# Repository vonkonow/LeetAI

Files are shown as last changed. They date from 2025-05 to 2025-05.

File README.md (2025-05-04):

# 🎹 Leet AI – A Tiny Synth Ensemble with AI-Powered Inspiration

Leet AI is a playful, pocket-sized synthesizer concept that explores what happens when many simple instruments work together—like a miniature electronic orchestra. Unlike traditional synths that try to do everything, Leet AI embraces a modular philosophy: multiple open-source, affordable units, each with a specific voice, combining to create something greater than the sum of their parts.

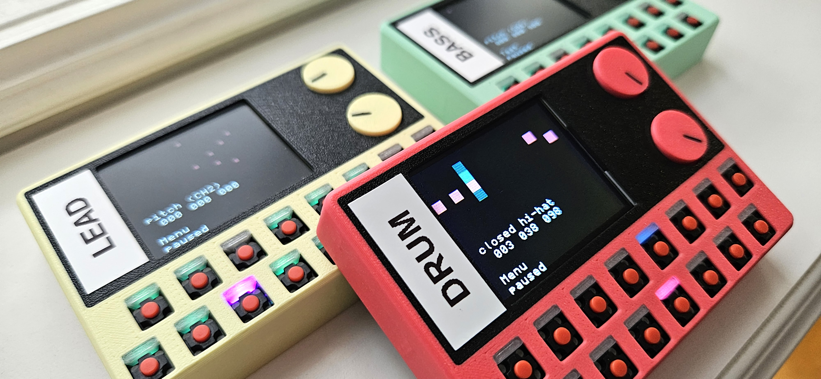
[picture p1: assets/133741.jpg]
group photo


---

## 🌟 Why Leet AI?

Synthesizers can be intimidating. Menus, shift-buttons, and buried features can kill creative flow. Leet AI is an attempt to bring back the fun—tiny instruments you can pick up, jam with, and let the AI surprise you with new melodic ideas. Whether you're a tinkerer, a musician, or just curious about AI and music, this project is for you.

---

## ✨ Features

- 🎵 **AI-powered inspiration**  
  Generate unique melodies, drum patterns, and variations using a diffusion-based AI model.

- 🔧 **Hackable and open-source**  
  Built with CircuitPython on an ESP32-S2—plug it in, and you're editing the firmware like a USB stick.

- 🎛️ **Minimalist design with deep control**  
  Dual rotary encoders with tilt navigation, RGB-backlit keys, and a full-color display keep you focused and in control.

- 📶 **Wireless orchestration**  
  A low-latency protocol keeps multiple units in sync.

- 🔋 **Fully portable**  
  Runs on a rechargeable 1000mAh LiPo battery. Jam anywhere.

---

## 📦 Hardware Specs

- **Size:** 86 x 60 x 15 mm (smaller than a deck of cards!)
- **Keys:** 16 RGB-backlit mechanical keys
- **Microcontroller:** ESP32-S2 (CircuitPython firmware)
- **Display:** 1.8” 160x128 TFT color screen
- **Encoders:** Dual magnetic rotary encoders with tilt function
- **Audio:** High-quality 112dB SNR DAC
- **Connectivity:** MIDI over USB-C, ESP-Now wireless sync
- **Power:** 1000mAh LiPo battery with onboard charging

---

# ▶️ **Demo video** 
demo (https://youtu.be/MnzYHhDXu_o)

---

## 🧪 Build Difficulty 

**Medium.** You'll need SMD soldering skills, a 3D printer, and some patience and curiosity.

---

## 🛠️ Development History

Leet AI combines the best aspects of three earlier open hardware projects: [**leet**](https://vonkonow.com/leet-synthesizer/), [**leet modular**](https://vonkonow.com/leet-modular/), and [**chip champ**](https://vonkonow.com/chipchamp/). Prototypes have evolved through countless iterations—from hand-wired mock-ups to a 12-key prototype and finally to the 16-key design that bridges sequencer and keyboard layouts.

---

## 🚧 Limitations (For Now)

This is still a conceptual prototype. While it’s fully functional for the demo, many features are hardcoded. Here’s what’s next on the roadmap:

- 🎚️ Real-time editing and melody creation  
- 🎵 Higher-fidelity audio engine and custom graphic module
- 🎛️ Instrument selection and sound design (ADSR, filters, etc.)  
- 🧠 Smarter AI integration with automatic Wi-Fi server connection  
- 🎹 Stacked octave mode  
- 🔊 Optional speaker  
- 🎶 AMY synth library support?

---

## 🛒 BOM / Estimated Cost

**Total cost per unit:** ~$24

---

## 💡 Contributing

Got ideas? Want to help improve the synth engine, optimize graphics, or design new enclosures? All contributions—code, hardware, or creative—are welcome!

### ➕ How to Contribute

1. Fork the repo  
2. Try the demo firmware  
3. Submit issues or pull requests  
4. Join the discussion on hardware, AI models, or interface design

---

## 📁 Repository Structure

```
/
├── firmware/       → CircuitPython source code
├── hardware/       → KiCad files, schematics, and PCB layout
├── enclosure/      → 3D models (Rhino & STL)
├── ai-server/      → getMusic setup, scripts and generation tools
├── docs/           → Build guide, BOM, and reference images
└── README.md       → Project overview
```

---

## ❤️ Special Thanks

Huge thanks to the creators and maintainers of open-source tools that made this project possible.  
Special gratitude to [**Adafruit**](https://www.adafruit.com/) for developing [**CircuitPython**](https://circuitpython.org/board/lolin_s2_mini/), which made firmware development approachable, flexible, and fun—even for hardware newcomers.  
Thanks also to the team behind [**synthio**](https://docs.circuitpython.org/en/latest/shared-bindings/synthio/), whose powerful audio capabilities laid the groundwork for expressive, real-time sound generation on microcontrollers.  
And to Microsoft Research for [**getMusic**](https://github.com/microsoft/muzic), and to all the explorers at the intersection of music, AI, and creative technology—your curiosity and generosity continue to inspire.

---

## 🧠 Imagine What’s Next

Leet AI is still early, but the concept is alive. With your feedback, forks, and experiments, this can grow into a truly modular, generative instrument playground.

---

## 🔗 [Visit the project website  ](https://vonkonow.com/leetai/)
## 📂 [Explore the GitHub repository  ](https://github.com/vonkonow/leetai)
## 📸 [Share your builds and music!](https://vonkonow.com/community/)

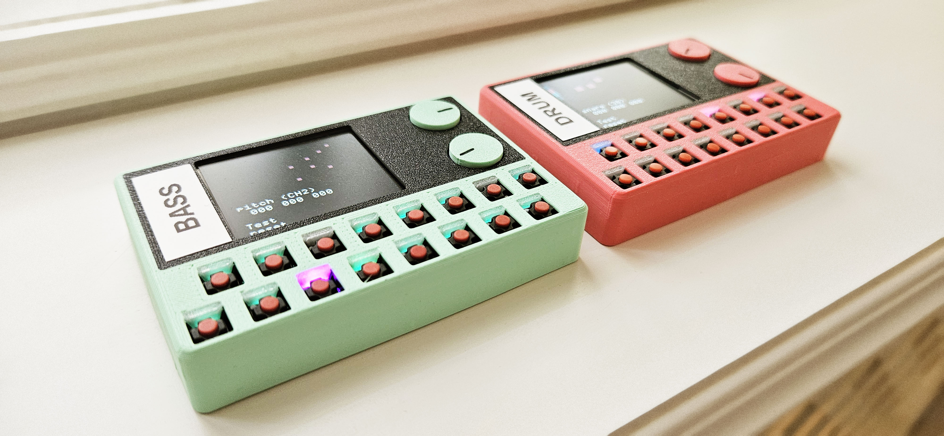
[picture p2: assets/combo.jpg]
DnB


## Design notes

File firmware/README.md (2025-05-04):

# 🎛️ CircuitPython code repository for the LeetAi devices. 
## Usage:
0. First time, you have to connect the device and flash a [CircuitPython image for ESP32S2](https://circuitpython.org/board/lolin_s2_mini/) with [this tool](https://adafruit.github.io/Adafruit_WebSerial_ESPTool/).
1. The device then appears as a new drive. Copy all files and folders in this directory to the device.
2. The code will run automatically and you now have a synth. Edit config/config.py to change its function (see below).

---

## ⚙️ Configuration

The file `config.py` defines each unit's role:

| Function | Description |
|---|---|
| `boss` | Manages the overall song structure |
| `pitch`  | Handles piano and bass lines |
| `pattern`| Drives drum patterns |
| `chords` | Generates chord progressions |
| `arp` | Plays arpeggios that follow chords |

---
## 📁 folder structure:
```
firmware/
├── README.md             # CircuitPython usage & setup instructions
├── boot.py               # Auto-run stub to launch main code on reset
├── code.py               # Entry-point script that wires everything together
│
├── config/               # User-tweakable settings and menus
│   ├── config.py         # Role definitions (boss, arp, chords, etc.) & parameters
│   └── menu.txt          # Text menu definitions shown on the display
│
├── src/                  # Core application code broken into two layers
│   ├── core/             # High-level “unit” drivers (boss, arp, pitch, …)
│   │   ├── boss.py       # Master song/section manager
│   │   ├── chords.py     # Chord progression engine
│   │   ├── pattern.py    # Drum-pattern sequencer
│   │   ├── pitch.py      # Melody & bass line handler
│   │   └── arp.py        # Real-time arpeggiator
│   │
│   └── common/           # Shared utilities & hardware abstractions
│       ├── audio.py      # Synth/audio helper routines
│       ├── hw.py         # Pin/encoder/button abstraction
│       ├── menu.py       # On-screen menu rendering & logic
│       ├── network.py    # Networking (Wi-Fi/OSC/etc.) support
│       ├── song.py       # Song data structures & serialization
│       └── ui.py         # Display & UI primitives
│
├── lib/                  # Bundled 3rd-party CircuitPython libraries/drivers
│   ├── adafruit_midi/      # MIDI bindings
│   ├── adafruit_imageload/ # Image-loading helper
│   ├── adafruit_st7735r.mpy # ST7735 display driver
│   ├── adafruit_wave.mpy    # WAV-sample playback driver
│   ├── neopixel.mpy         # WS2812 “NeoPixel” LED driver
│   └── font.bmp             # Built-in font bitmap
│
└── assets/               # Static resources bundled into filesystem
    ├── images/           # UI graphics, icons, etc.
    ├── audio/            # Samples and wavetable files
    └── arpai.bin         # Demo song (used by boss)
```
---

## 🧰 Hardware Versions

| Version | Features |
|---|---|
| **1.0** | 12 keys + analog encoders |
| **1.1** | 16 keys (new layout) + digital encoders |

---

## 🧪 Development Notes

I've used AI extensively for code refactoring, improvements and error handling. It's a work in progress and likely a few bugs left — but it's definitely more robust than before :)

---
## ❤️ Special Thanks

Huge thanks to the creators and maintainers of open-source tools that made this project possible.  
- Special gratitude to [**Adafruit**](https://www.adafruit.com/) for developing [**CircuitPython**](https://circuitpython.org/board/lolin_s2_mini/), which made firmware development approachable, flexible, and fun—even for hardware newcomers.  
- Thanks also to the team behind [**synthio**](https://docs.circuitpython.org/en/latest/shared-bindings/synthio/), whose powerful audio capabilities laid the groundwork for expressive, real-time sound generation on microcontrollers.  
- And to Microsoft Research for [**getMusic**](https://github.com/microsoft/muzic), and to all the explorers at the intersection of music, AI, and creative technology—your curiosity and generosity continue to inspire.

---
## 🚀 Future Development

Plenty remains to be done. The current demo uses mostly hard-coded elements, so unlocking its full potential will require:

- 🎼 **Melody & pattern editor**
- 🎧 **Audio optimization**  *(Better sample rates, pitch control, lower CPU usage)*
- 🖼️ **Optimized graphics**  *(Smoother animations with less CPU load)*
- 🎚️ **Instrument sound selection and parameter tuning**  *(Velocity, bend, swing, ADSR, filters)*
- 🔀 **Stacked octave mode**  *(Multiple units act as one extended synth)*
- 🌐 **Ai server connection**  *(Currently manual)*
- 🔊 **Maybe a built-in speaker?**
- 🎵 **AMY synth library integration?**

I will probably start with a custom circuitpython fork with new libraries for audio and graphics...

---
## 💡 Contributing

Got ideas? Want to help improve the synth engine, optimize graphics, or design new enclosures? All contributions—code, hardware, or creative—are welcome!

### ➕ How to Contribute

1. Fork the repo  
2. Try the demo firmware  
3. Submit issues or pull requests  
4. Join the discussion on hardware, AI models, or interface design

### 🧠 Imagine What's Next

Leet AI is still early, but the concept is alive. With your feedback, forks, and experiments, this can grow into a truly modular, generative instrument playground.

---

🔗 [Visit the project website  ](https://vonkonow.com/leetai/)
📂 [Explore the GitHub repository  ](https://github.com/vonkonow/leetai)
📸 [Share your builds and music!](https://vonkonow.com/community/)

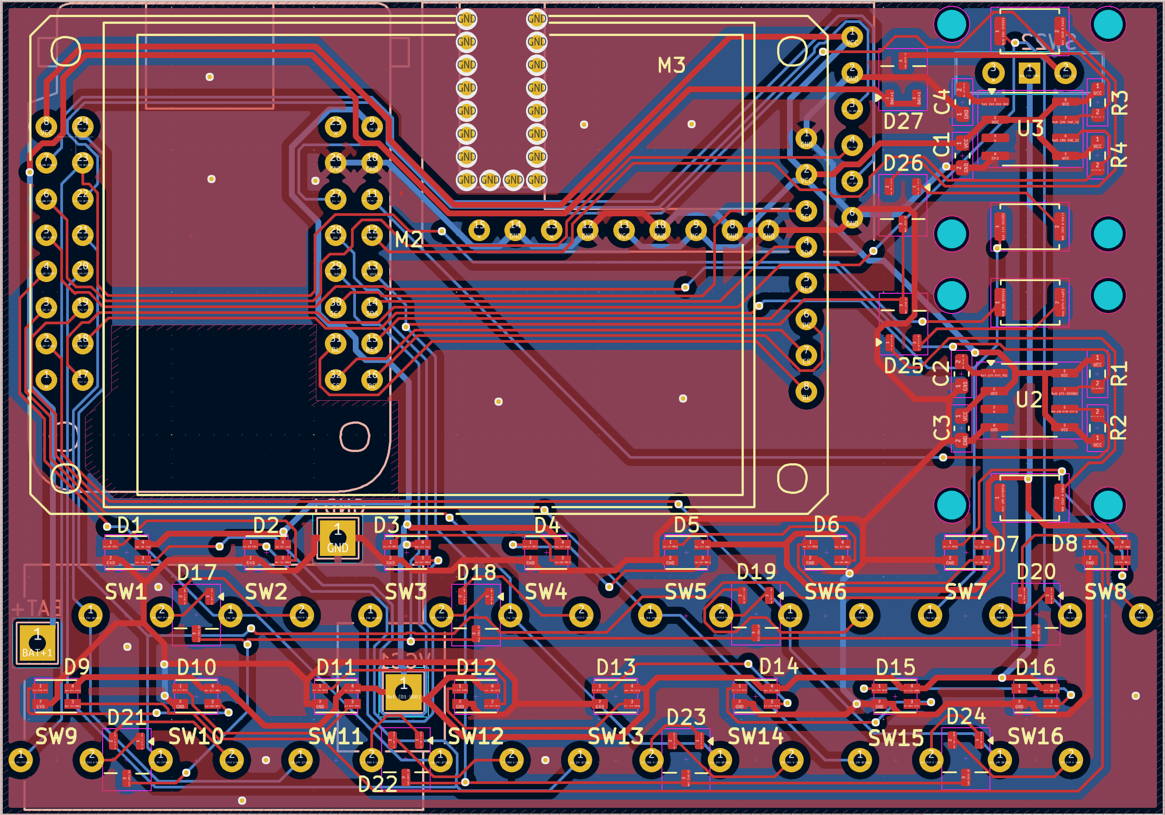
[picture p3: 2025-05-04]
hardware/_pcb.png

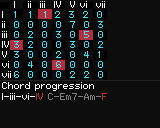
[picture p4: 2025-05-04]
firmware/assets/images/chord3.bmp

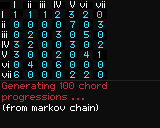
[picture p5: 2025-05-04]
firmware/assets/images/generate.bmp

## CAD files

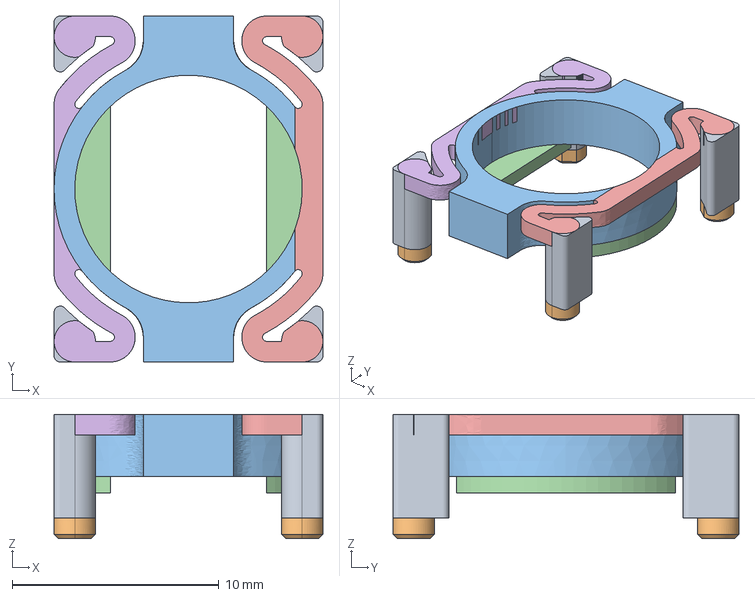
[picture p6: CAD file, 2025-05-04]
enclosure/encoder_main.stp
13.0 x 16.7 x 6.00 mm

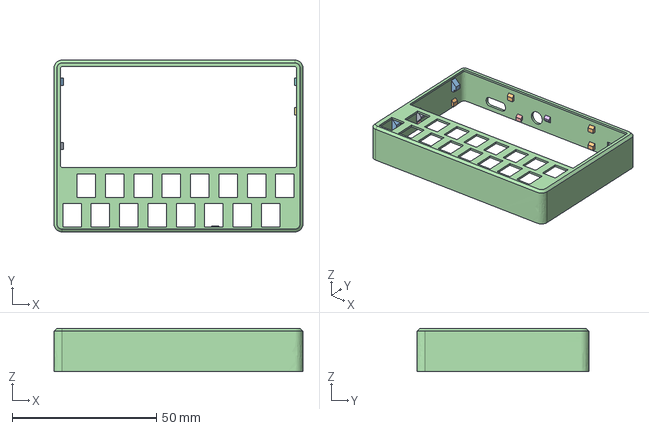
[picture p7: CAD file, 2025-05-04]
enclosure/case_main.stp
86.2 x 59.5 x 15.0 mm

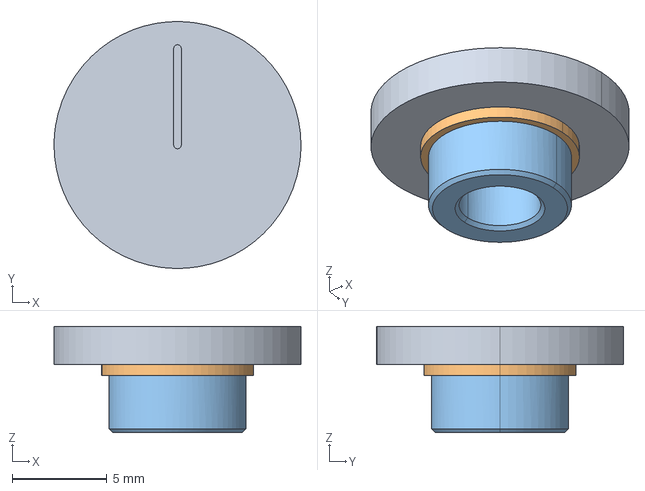
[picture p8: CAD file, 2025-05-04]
enclosure/encoder_knob.stp
13.0 x 13.0 x 5.60 mm

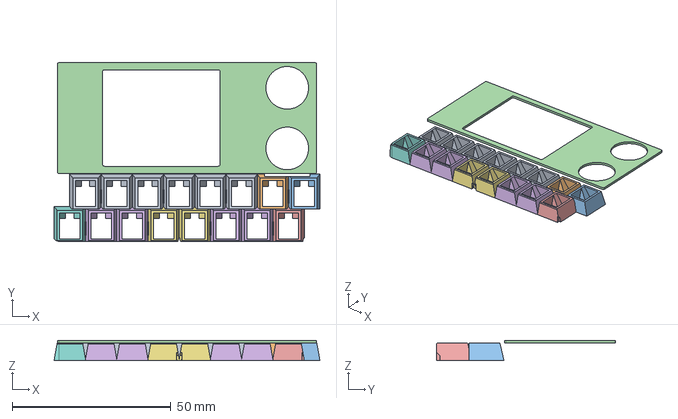
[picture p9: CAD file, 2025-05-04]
enclosure/case_black.stp
83.7 x 56.2 x 6.40 mm

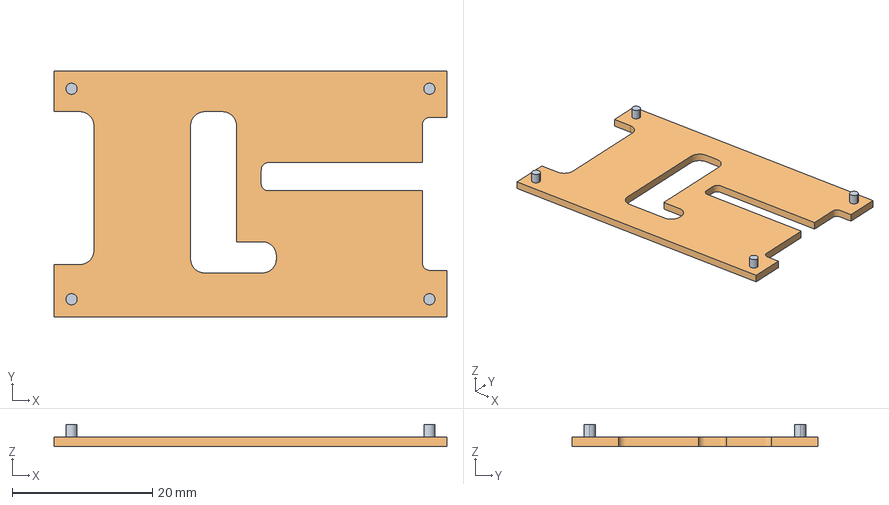
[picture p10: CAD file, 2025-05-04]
enclosure/support_lcd.stp
56.0 x 35.0 x 3.18 mm

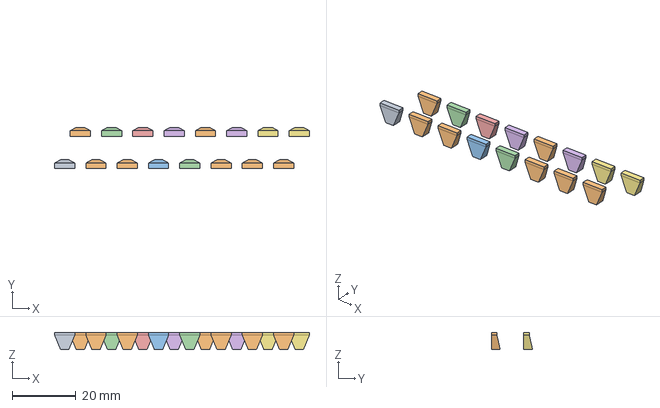
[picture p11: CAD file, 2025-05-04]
enclosure/case_led.stp
80.1 x 13.0 x 5.38 mm

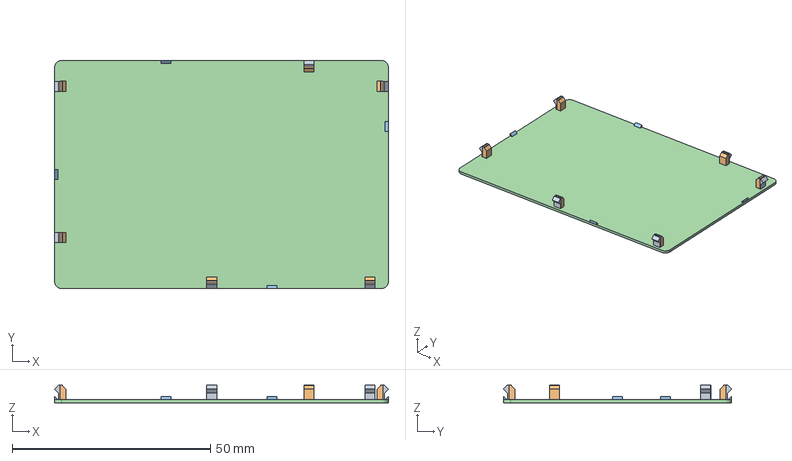
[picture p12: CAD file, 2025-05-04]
enclosure/case_lid.stp
84.2 x 57.5 x 4.50 mm

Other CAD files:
enclosure/case_black.stl
enclosure/case_led.stl
enclosure/case_lid.stl
enclosure/case_main.stl
enclosure/encoder_knob.stl
enclosure/encoder_main.stl
enclosure/support_lcd.stl

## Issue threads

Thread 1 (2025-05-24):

BOM? Charger chip?

GeoffreyPlitt, 2025-05-24:
Cool project!
Can you add a BOM?
What's the part# of the charger chip?

vonkonow, 2025-06-01:
Checkout https://vonkonow.com/leetai/ that has a simple bom.
the charger is a pcb with TP4056, like this: https://www.aliexpress.com/item/1005004427739715.html?

Closed 2025-06-01.

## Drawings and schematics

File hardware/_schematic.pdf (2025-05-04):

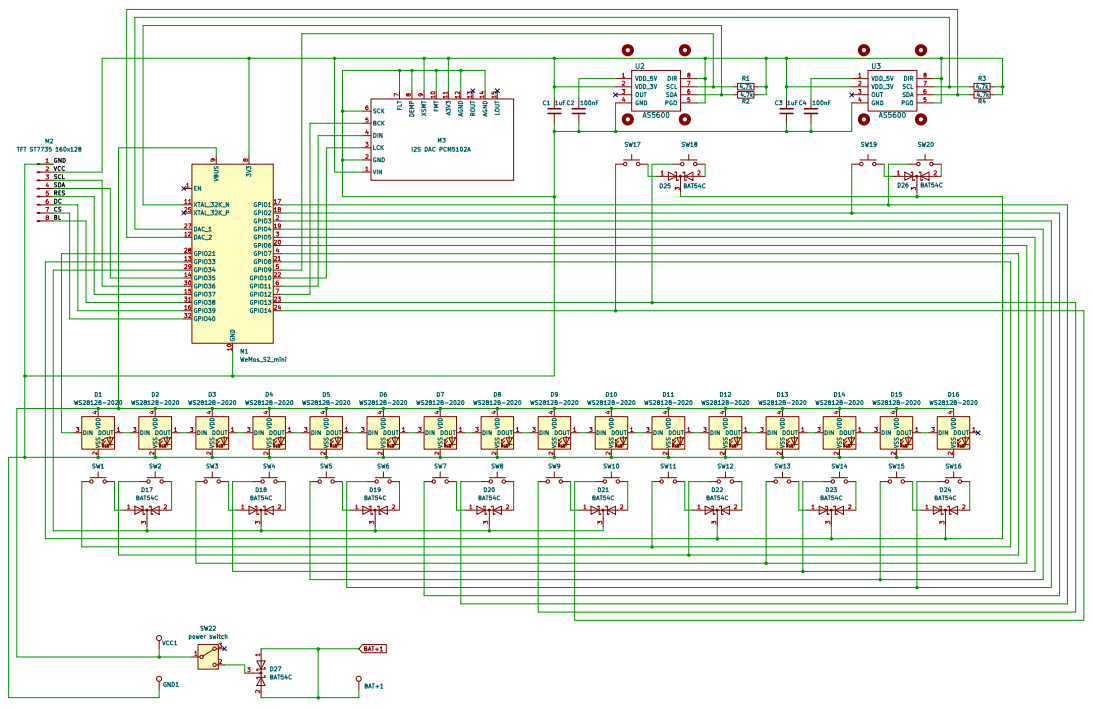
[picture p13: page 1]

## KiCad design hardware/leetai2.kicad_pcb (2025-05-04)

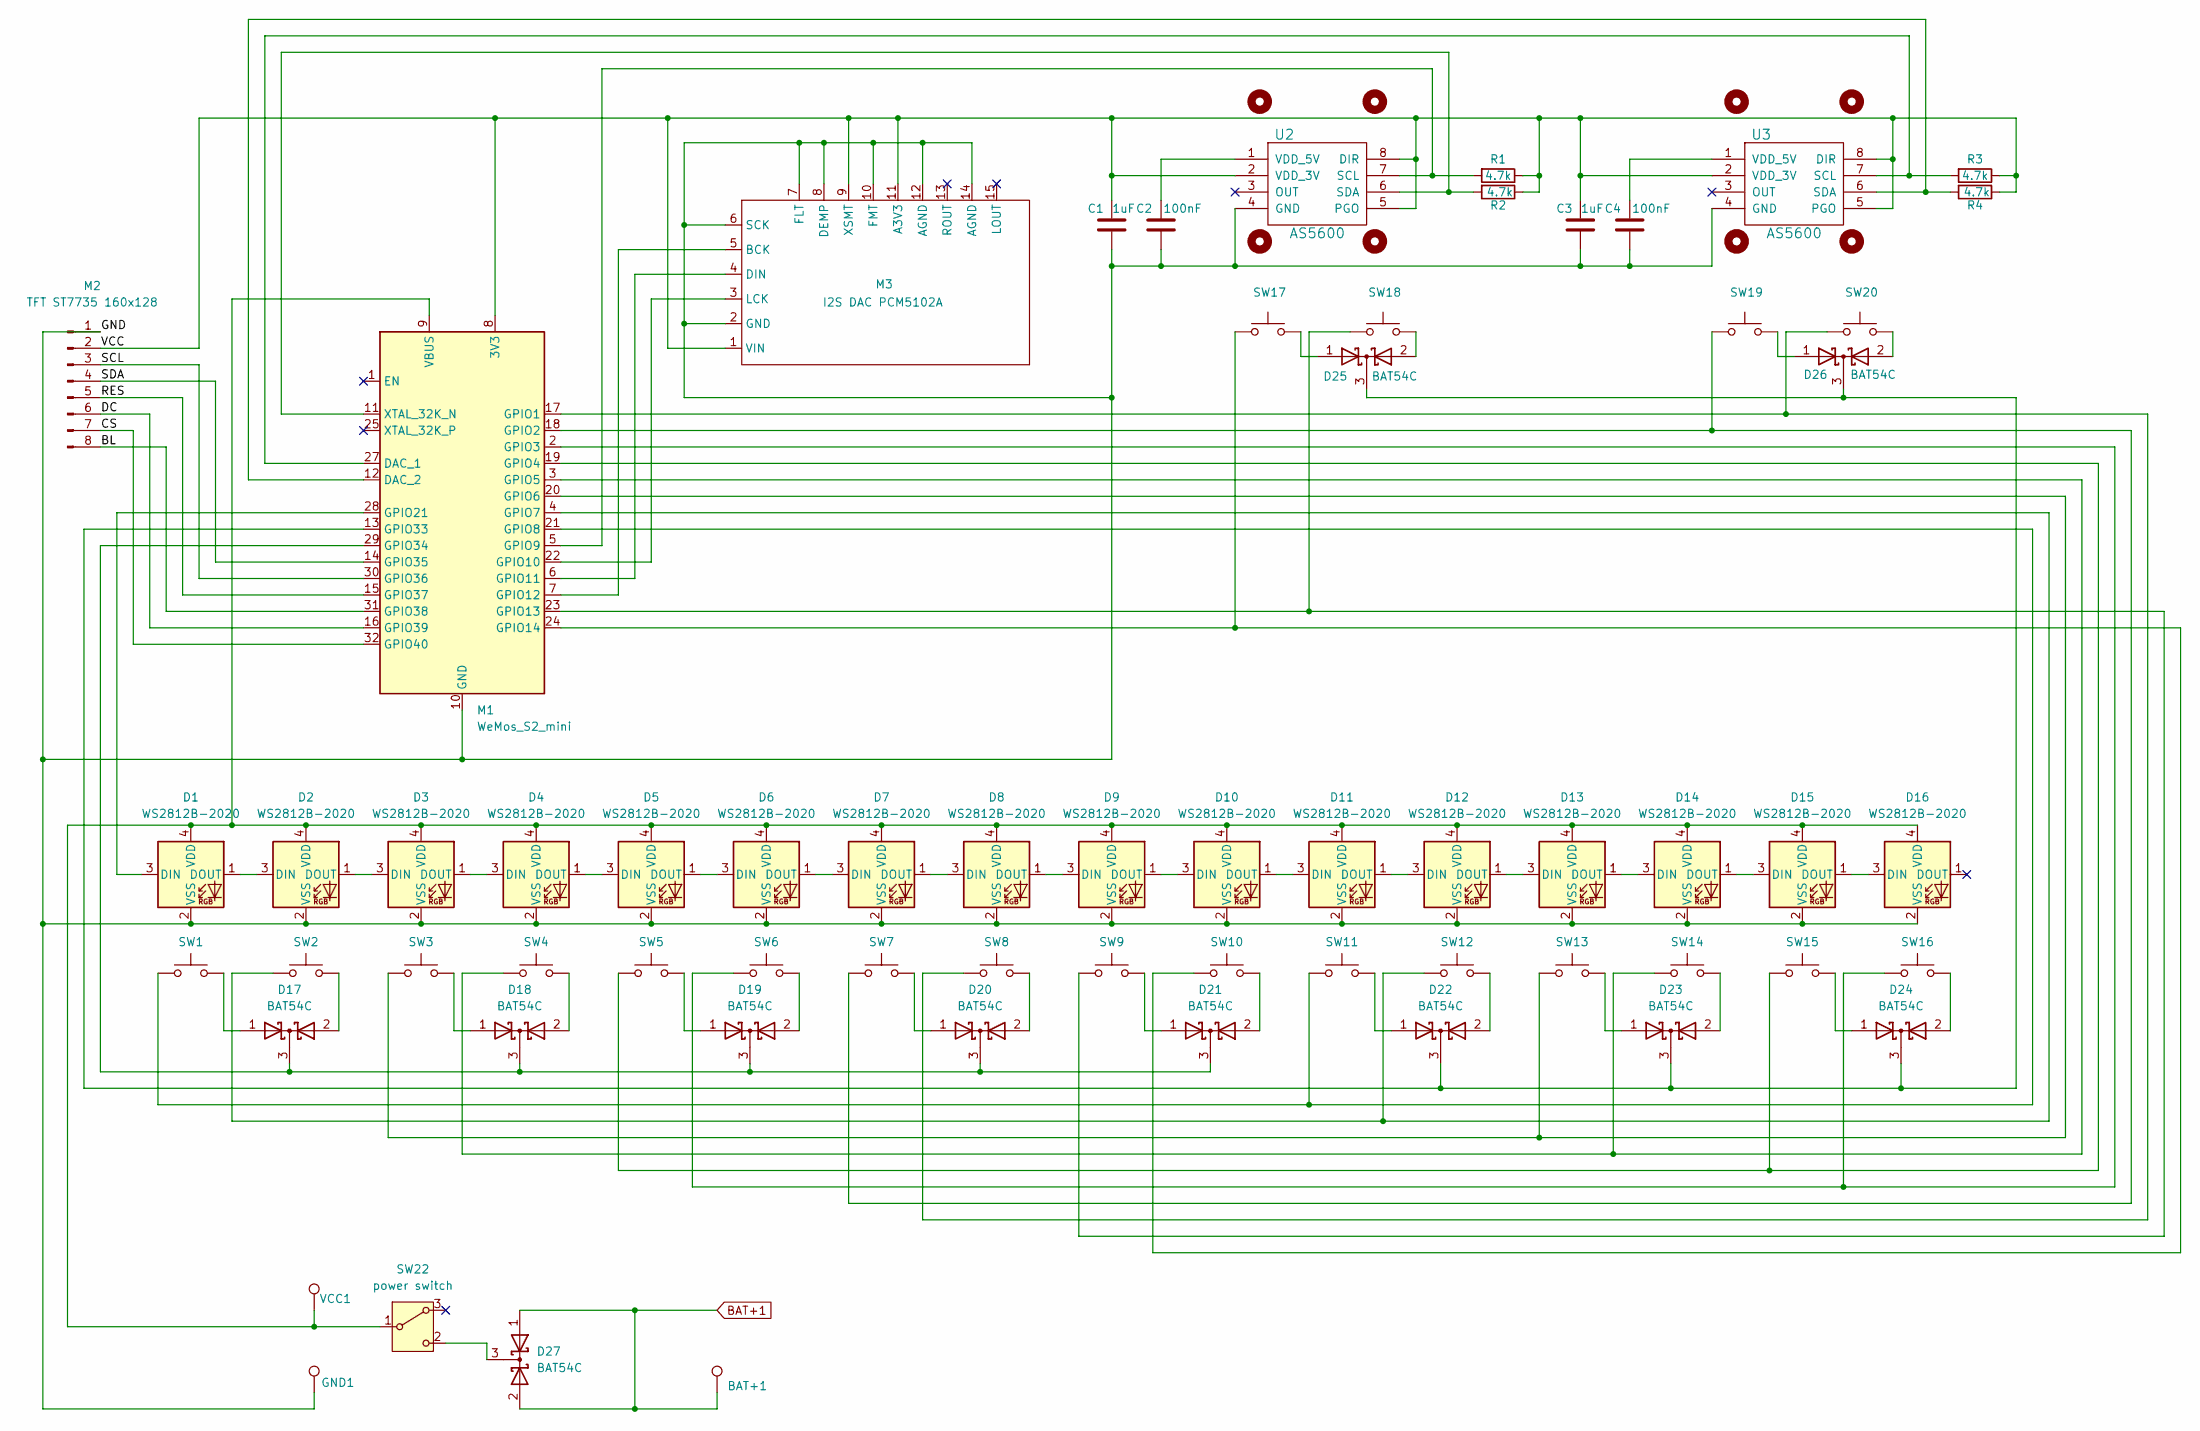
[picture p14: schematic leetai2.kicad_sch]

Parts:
BAT+1: Conn_01x01_Female; TestPoint_THTPad_2.5x2.5mm_Drill1.2mm
C1, C3: 1uF; C_0603_1608Metric_Pad1.08x0.95mm_HandSolder
C2, C4: 100nF; C_0603_1608Metric_Pad1.08x0.95mm_HandSolder
D1, D2, D3, D4, D5, D6, D7, D8, D9, D10, D11, D12, D13, D14, D15, D16: WS2812B-2020; LED_WS2812B-2020_PLCC4_2.0x2.0mm
D17, D18, D19, D20, D21, D22, D23, D24, D25, D26, D27: BAT54C; TSOT-23
GND1: Conn_01x01_Female; TestPoint_THTPad_2.5x2.5mm_Drill1.2mm
H1, H2, H3, H4, H5, H6, H7, H8: MountingHole; MountingHole_2mm
M1: WeMos_S2_mini; wemos_s2_mini
M2: TFT ST7735 160x128
M3: I2S DAC PCM5102A; I2S DAC 5102
R1, R2, R3, R4: 4.7k; R_0603_1608Metric_Pad0.98x0.95mm_HandSolder
SW1, SW2, SW3, SW4, SW5, SW6, SW7, SW8, SW9, SW10, SW11, SW12, SW13, SW14, SW15, SW16: SW_Omron_B3FS; switch_mouse_kailh_6x6
SW17, SW18, SW19, SW20: SW_Omron_B3FS; SW_Push_SPST_NO_Alps_SKRK
SW22: power switch; SW_Slide-03_Wuerth-WS-SLTV_10x2.5x6.4_P2.54mm
U2, U3: AS5600; SOIC-8_3.9x4.9mm_P1.27mm; Manufacturer Part Number AS5600-ASOM
VCC1: Conn_01x01_Female; TestPoint_THTPad_2.5x2.5mm_Drill1.2mm

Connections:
/BL: M1.31 (GPIO38), M2.8
/CS: M1.32 (GPIO40), M2.7
/DC: M1.16 (GPIO39), M2.6
/GND: C1.2, C2.1, C3.2, C4.1, D1.2 (VSS), D2.2 (VSS), D3.2 (VSS), D4.2 (VSS), D5.2 (VSS), D6.2 (VSS), D7.2 (VSS), D8.2 (VSS), D9.2 (VSS), D10.2 (VSS), D11.2 (VSS), D12.2 (VSS), D13.2 (VSS), D14.2 (VSS), D15.2 (VSS), D16.2 (VSS), GND1.1, M1.10 (GND), M1.26 (GND), M2.1, M3.2 (GND), M3.6 (SCK), M3.7 (FLT), M3.8 (DEMP), M3.10 (FMT), M3.12 (AGND), M3.14 (AGND), U2.4 (GND), U3.4 (GND)
/RES: M1.15 (GPIO37), M2.5
/SCL: M1.30 (GPIO36), M2.3
/SDA: M1.14 (GPIO35), M2.4
/VCC: C1.1, C3.1, M1.8 (3V3), M2.2, M3.1 (VIN), M3.9 (XSMT), M3.11 (A3V3), R1.1, R2.1, R3.1, R4.1, U2.2 (VDD_3V), U2.5 (PGO), U2.8 (DIR), U3.2 (VDD_3V), U3.5 (PGO), U3.8 (DIR)
BAT+1: BAT+1.1, D27.1 (A), D27.2 (A); also elsewhere on the board
unnamed: D1.3 (DIN), M1.28 (GPIO21)
unnamed: D1.1 (DOUT), D2.3 (DIN)
unnamed: D1.4 (VDD), D2.4 (VDD), D3.4 (VDD), D4.4 (VDD), D5.4 (VDD), D6.4 (VDD), D7.4 (VDD), D8.4 (VDD), D9.4 (VDD), D10.4 (VDD), D11.4 (VDD), D12.4 (VDD), D13.4 (VDD), D14.4 (VDD), D15.4 (VDD), D16.4 (VDD), M1.9 (VBUS), SW22.1 (B), VCC1.1
unnamed: D2.1 (DOUT), D3.3 (DIN)
unnamed: D3.1 (DOUT), D4.3 (DIN)
unnamed: D4.1 (DOUT), D5.3 (DIN)
unnamed: D5.1 (DOUT), D6.3 (DIN)
unnamed: D6.1 (DOUT), D7.3 (DIN)
unnamed: D7.1 (DOUT), D8.3 (DIN)
unnamed: D8.1 (DOUT), D9.3 (DIN)
unnamed: D9.1 (DOUT), D10.3 (DIN)
unnamed: D10.1 (DOUT), D11.3 (DIN)
unnamed: D11.1 (DOUT), D12.3 (DIN)
unnamed: D12.1 (DOUT), D13.3 (DIN)
unnamed: D13.1 (DOUT), D14.3 (DIN)
unnamed: D14.1 (DOUT), D15.3 (DIN)
unnamed: D15.1 (DOUT), D16.3 (DIN)
unnamed: D17.1 (A), SW1.2
unnamed: D17.2 (A), SW2.2
unnamed: D17.3 (K), D18.3 (K), D19.3 (K), D20.3 (K), D21.3 (K), M1.29 (GPIO34)
unnamed: D18.1 (A), SW3.2
unnamed: D18.2 (A), SW4.2
unnamed: D19.1 (A), SW5.2
unnamed: D19.2 (A), SW6.2
unnamed: D20.1 (A), SW7.2
unnamed: D20.2 (A), SW8.2
unnamed: D21.1 (A), SW9.2
unnamed: D21.2 (A), SW10.2
unnamed: D22.1 (A), SW11.2
unnamed: D22.2 (A), SW12.2
unnamed: D22.3 (K), D23.3 (K), D24.3 (K), D25.3 (K), D26.3 (K), M1.13 (GPIO33)
unnamed: D23.1 (A), SW13.2
unnamed: D23.2 (A), SW14.2
unnamed: D24.1 (A), SW15.2
unnamed: D24.2 (A), SW16.2
unnamed: D25.1 (A), SW17.2
unnamed: D25.2 (A), SW18.2
unnamed: D26.1 (A), SW19.2
unnamed: D26.2 (A), SW20.2
unnamed: D27.3 (K), SW22.2 (C)
unnamed: M1.27 (DAC_1), R3.2, U3.7 (SCL)
unnamed: M1.12 (DAC_2), R4.2, U3.6 (SDA)
unnamed: M1.17 (GPIO1), SW8.1, SW20.1
unnamed: M1.18 (GPIO2), SW7.1, SW19.1
unnamed: M1.2 (GPIO3), SW6.1, SW16.1
unnamed: M1.19 (GPIO4), SW5.1, SW15.1
unnamed: M1.3 (GPIO5), SW4.1, SW14.1
unnamed: M1.20 (GPIO6), SW3.1, SW13.1
unnamed: M1.4 (GPIO7), SW2.1, SW12.1
unnamed: M1.21 (GPIO8), SW1.1, SW11.1
unnamed: M1.5 (GPIO9), R1.2, U2.7 (SCL)
unnamed: M1.22 (GPIO10), M3.3 (LCK)
unnamed: M1.6 (GPIO11), M3.4 (DIN)
unnamed: M1.7 (GPIO12), M3.5 (BCK)
unnamed: M1.23 (GPIO13), SW9.1, SW18.1
unnamed: M1.24 (GPIO14), SW10.1, SW17.1
unnamed: M1.11 (XTAL_32K_N), R2.2, U2.6 (SDA)
unnamed: C2.2, U2.1 (VDD_5V)
unnamed: C4.2, U3.1 (VDD_5V)

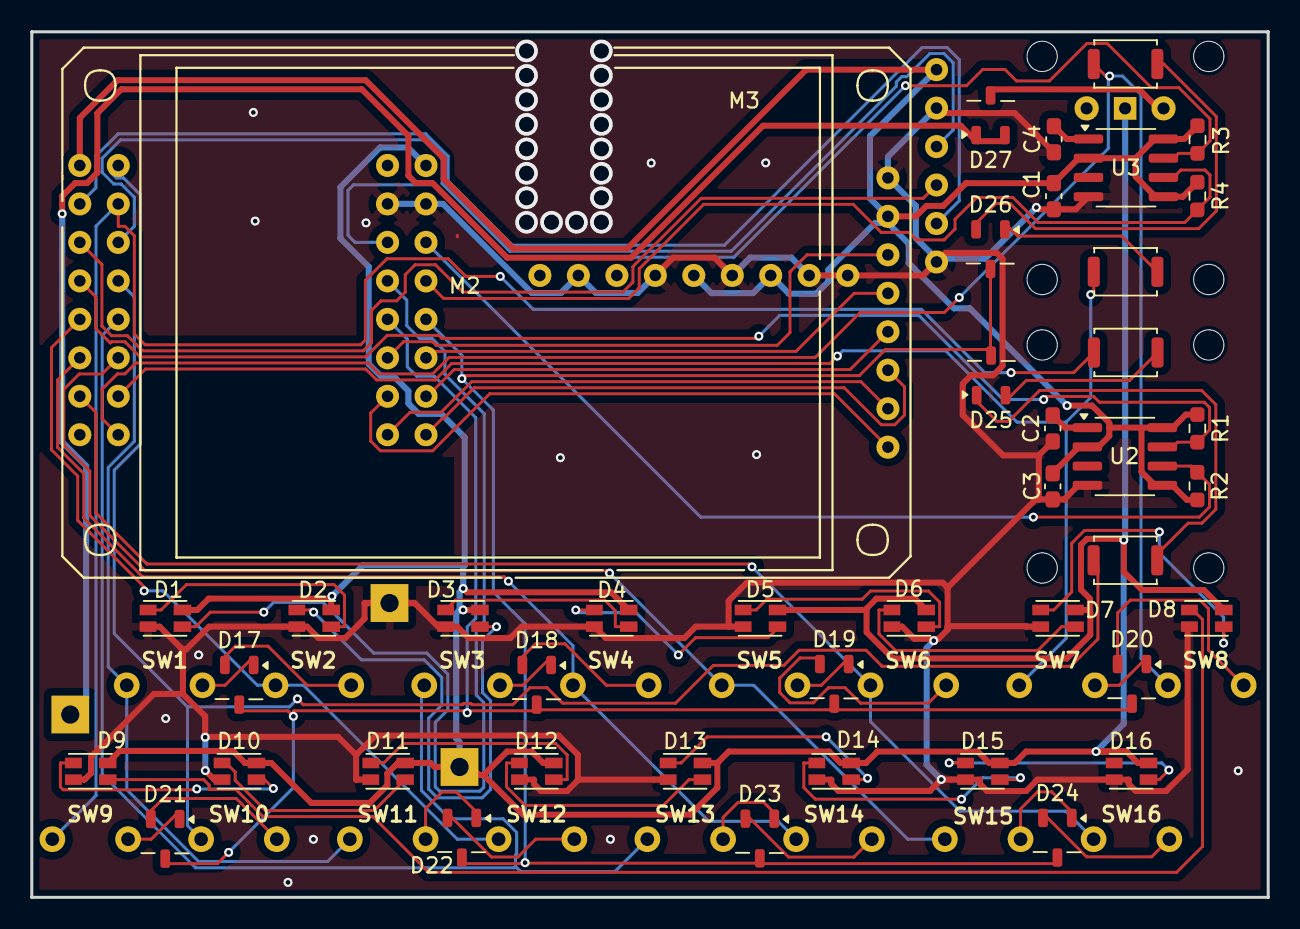
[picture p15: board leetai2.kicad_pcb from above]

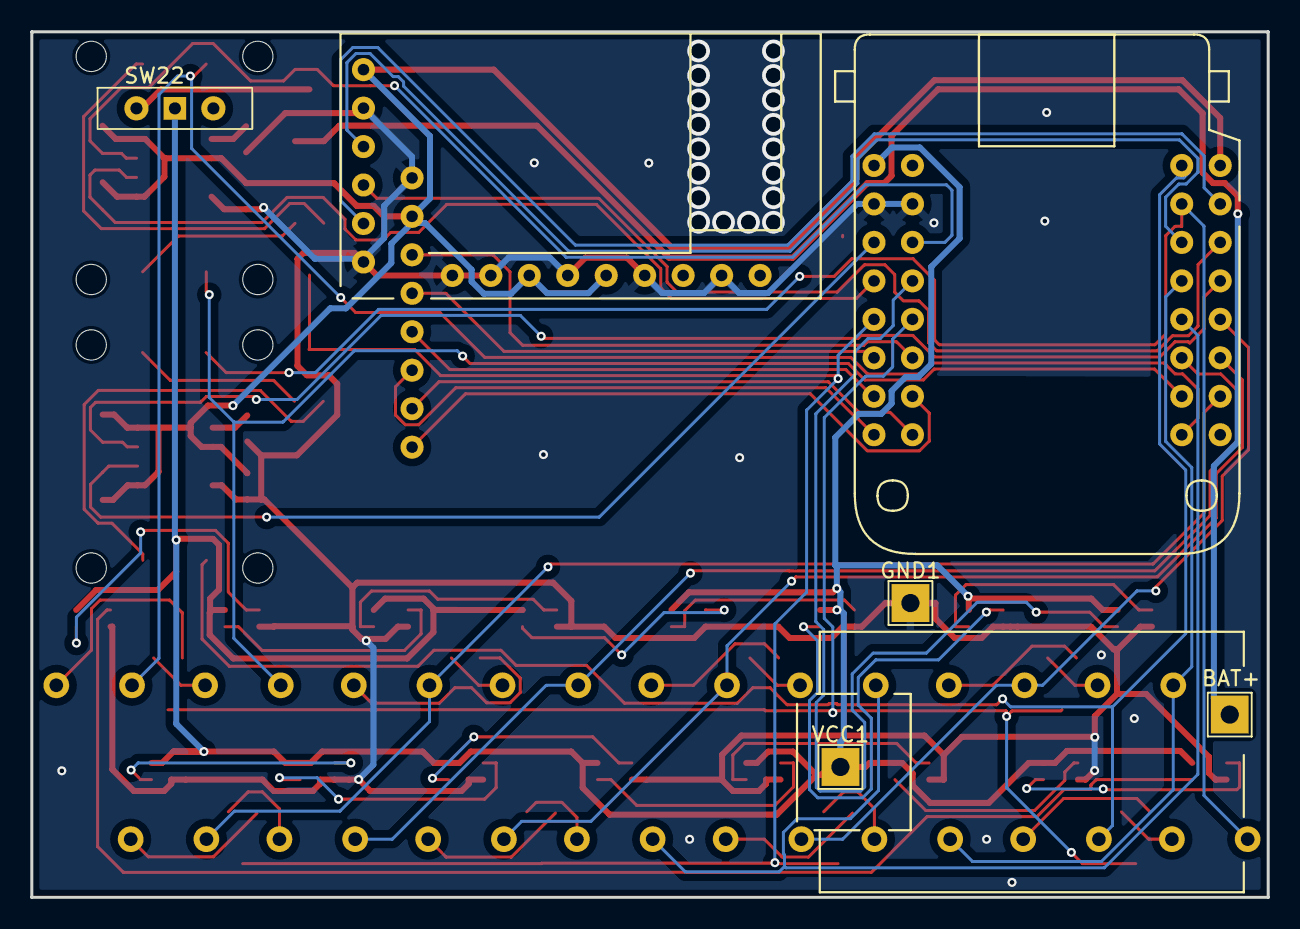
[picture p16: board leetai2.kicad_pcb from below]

Board: 2 copper layers, 81.6 x 57.2 mm, 72 parts (5 on the bottom side), 68 nets.

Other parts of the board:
BAT+: Conn_01x01_Female; TestPoint_THTPad_2.5x2.5mm_Drill1.2mm

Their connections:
BAT+1: BAT+.1; also elsewhere on the board

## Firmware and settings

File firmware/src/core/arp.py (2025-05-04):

#------10|-------20|-------30|-------40|-------50|-------60|-------70|-------80|
# ******************************************************************************
#                                                                                          
#              /$$$$$$   /$$$$$$   /$$$$$$ 
#             |____  $$ /$$__  $$ /$$__  $$
#              /$$$$$$$| $$  \__/| $$  \ $$
#             /$$__  $$| $$      | $$  | $$
#            |  $$$$$$$| $$      | $$$$$$$/
#             \_______/|__/      | $$____/ 
#                                | $$      
#                                |__/      
# Mockup to show how an arpeggiator could work, (hardcoded for demovideo)
# It recieves "scale packets" from chords unit that transposes the arpeggio
# 
# Todo:
#   *   proper graphics (uses fake images today)
#   *   add support for 1.1 hardware (only tested on 1.0)
# Done:
#   250501:
#     x major code refactoring and cleanup:
#       directory structure, common modules, manager classes and error handling
#
# ******************************************************************************
import config.config as config
from src.common import hw
import espnow									                  # type: ignore
import time										                  # type: ignore
import displayio                       		                      # type: ignore
import adafruit_imageload                                         # type: ignore
from src.common.ui import DisplayManager, colorwheel
from src.common.network import PacketHandler, NetworkError, PacketSendError, PacketReadError, SongSendError
from src.common.menu import MenuManager


class Field:
    """Handles the display field for the arpeggiator pattern"""
    def __init__(self, display_group=None, sprite_sheet=None, palette=None, x_start=40, y_start=0, x_max=8, y_max=8, tile_width=10, tile_height=10):
        self.display_group = display_group
        self.sprite_sheet = sprite_sheet
        self.palette = palette
        self.x_start = x_start
        self.y_start = y_start
        self.x_max = x_max
        self.y_max = y_max
        self.tile_width = tile_width
        self.tile_height = tile_height
        
        # Create sprite grid
        self.grid = displayio.TileGrid(
            self.sprite_sheet,
            pixel_shader=self.palette,
            width=self.x_max,
            height=self.y_max,
            tile_width=self.tile_width,
            tile_height=self.tile_height,
            x=self.x_start,
            y=self.y_start
        )
        self.display_group.append(self.grid)

    def reset(self, value=0):
        """Reset all tiles to the given value"""
        for y in range(self.y_max):
            for x in range(self.x_max):
                self.grid[x, y] = value

    def setBlock(self, x, y, value):
        """Set a specific tile to the given value"""
        self.grid[x, y] = value

    def hLine(self):
        """Draw a horizontal line"""
        for x in range(self.x_max):
            self.grid[x, 0] = config.DEFAULT_TILE_VALUE

class Image:
    """Handles background images for the arpeggiator"""
    def __init__(self, filename, display_group=None):
        self.display_group = display_group
        self.filename = f"assets/images/{filename}"  # Add assets/images/ prefix
        self.sprite = None
        self.sprite_grid = None
        self.load_image()

    def load_image(self):
        """Load the background image"""
        if self.sprite_grid:
            self.display_group.remove(self.sprite_grid)
        self.sprite = displayio.OnDiskBitmap(self.filename)
        self.sprite_grid = displayio.TileGrid(
            self.sprite,
            pixel_shader=self.sprite.pixel_shader,
            x=0,
            y=config.BACKGROUND_Y_OFFSET  # Use config value for y-offset
        )
        self.display_group.append(self.sprite_grid)

    def replace(self, filename):
        """Replace the current background image"""
        self.filename = f"assets/images/{filename}"  # Add assets/images/ prefix
        self.load_image()

class ArpeggiatorState:
    """Manages the arpeggiator's internal state"""
    def __init__(self):
        self.mode = config.PLAYBACK_STATES["clear"]
        self.mute = 0
        self.ticks_per_beat = config.TICKS_PER_BEAT
        self.max_ticks = config.MAX_TICKS
        self.tempo = config.TEMPO
        self.denominator = config.DENOMINATOR
        self.start_time = time.monotonic()
        self.old_note = 0
        self.arp_pos = 0
        self.arp_notes = []
        self.chord_notes = []
        self.scale_notes = []
        self.arp2d = [[],[],[],[]]
        self.pos = 0
        
        # Calculate time conversion factors
        self.tick_to_time = (60 * 4) / (self.tempo * self.ticks_per_beat * self.denominator)
        self.time_to_tick = (self.tempo * self.ticks_per_beat * self.denominator) / (60 * 4)

    def update_scale(self, scale_start, scale):
        """Update scale and chord notes based on new scale"""
        self.scale_notes = [s + scale_start for s in scale]
        
        # Update chord notes
        self.chord_notes = []
        for a in range(0,5,2):
            note = scale[a] + scale_start
            while note > config.MAX_NOTE:
                note -= 12
            while note < config.MIN_NOTE:
                note += 12
            self.chord_notes.append(note)
        self.chord_notes.sort()

        # Update arpeggiator notes
        arp = config.DEFAULT_ARP_PATTERN
        self.arp_notes = [self.chord_notes[a] for a in arp]

    def reset(self):
        """Reset state to initial values"""
        self.start_time = time.monotonic()
        self.arp_pos = len(self.arp_notes) - 1 if self.arp_notes else 0
        self.pos = 0
        self.arp2d = [[],[],[],[]]

    def initialize_scale(self, scale_start=60):
        """Initialize scale with default values"""
        scale = [0, 2, 4, 5, 7, 9, 11]
        self.update_scale(scale_start, scale)

class ArpeggiatorUI:
    """Handles all UI-related operations for the arpeggiator"""
    def __init__(self, display_manager, hw):
        self.display_manager = display_manager
        self.hw = hw
        self.field = None
        self.background = None
        
        # Load sprite sheet
        self.sprite_sheet, self.palette = adafruit_imageload.load(
            "assets/images/10x10.bmp",
            bitmap=displayio.Bitmap,
            palette=displayio.Palette
        )
        
        self.initialize_ui()

    def initialize_ui(self):
        """Initialize UI components"""
        # Create field
        self.field = Field(
            display_group=self.hw.displayGroup,
            sprite_sheet=self.sprite_sheet,
            palette=self.palette,
            x_start=config.XSTART,
            y_start=config.YSTART,
            x_max=config.FIELD_X_MAX,
            y_max=config.FIELD_Y_MAX,
            tile_width=config.FIELD_TILE_WIDTH,
            tile_height=config.FIELD_TILE_HEIGHT
        )
        
        # Create background
        self.background = Image("arp0.bmp", self.hw.displayGroup)
        self.hw.display.refresh()

    def update_pattern(self, field, arp2d, pos):
        """Update the pattern display"""
        field.reset(0)
        for y in range(4):
            for x in arp2d[y]:
                field.setBlock(x, y, config.PATTERN_ACTIVE_TILE)
        field.setBlock(pos % config.FIELD_X_MAX, int(pos / config.FIELD_X_MAX), config.PATTERN_CURRENT_TILE)
        self.hw.display.refresh()

    def update_leds(self, notes, active_notes=None):
        """Update LED states"""
        if active_notes is None:
            active_notes = []
            
        # Clear all LEDs first
        for i in range(config.NEOPIXEL_NUM):
            self.hw.pixels[i] = config.LED_OFF_COLOR
            
        # Update LEDs for active notes
        for note in active_notes:
            self.hw.pixels[note % config.NEOPIXEL_NUM] = config.LED_ACTIVE_COLOR
            
        # Update LEDs for arpeggiator notes
        for note in notes:
            self.hw.pixels[note % config.NEOPIXEL_NUM] = config.LED_ACTIVE_COLOR

    def update_background(self, scale_start):
        """Update background image based on scale"""
        if scale_start == config.SCALE_C:
            self.background.replace("arp0.bmp")
        elif scale_start == config.SCALE_G:
            self.background.replace("arp1.bmp")
        elif scale_start == config.SCALE_A:
            self.background.replace("arp2.bmp")
        elif scale_start == config.SCALE_F:
            self.background.replace("arp3.bmp")
        self.hw.display.refresh()

class ArpeggiatorNetwork:
    """Handles all network-related operations for the arpeggiator"""
    def __init__(self, hw, instrument_id, peer_broadcast):
        self.hw = hw
        self.instrument_id = instrument_id
        self.peer_broadcast = peer_broadcast
        self.esp = None
        self.packet_handler = None
        self.initialize_network()

    def initialize_network(self):
        """Initialize ESP-NOW and packet handler"""
        if config.MODE == "arp":
            try:
                self.esp = espnow.ESPNow()
                self.peer_broadcast = espnow.Peer(mac=config.MAC_BROADCAST)
                self.esp.peers.append(self.peer_broadcast)
                self.packet_handler = PacketHandler(self.esp, self.instrument_id, self.peer_broadcast)
            except RuntimeError as e:
                if "Already running" in str(e):
                    # ESP-NOW is already initialized, reuse the instance
                    self.esp = espnow.ESPNow()
                    self.packet_handler = PacketHandler(self.esp, self.instrument_id, self.peer_broadcast)
                else:
                    raise

    def handle_packet(self, packet):
        """Process incoming network packet"""
        try:
            return self.packet_handler.handle_packet(packet)
        except PacketReadError as e:
            raise
        except Exception as e:
            raise

    def send_packet(self, packet_type, args):
        """Send a packet over the network"""
        try:
            self.packet_handler.send_packet(packet_type, args)
        except PacketSendError as e:
            raise
        except Exception as e:
            raise

    def send_note(self, note, intensity):
        """Send a note packet"""
        self.send_packet('l', [self.instrument_id, note, intensity])

class ArpeggiatorInput:
    """Handles all input-related operations for the arpeggiator"""
    def __init__(self, hw, state, ui, network):
        self.hw = hw
        self.state = state
        self.ui = ui
        self.network = network

    def handle_key_input(self):
        """Process key input events"""
        for i in range(12):
            val, new = self.hw.key_change(i)
            if new and val:
                self.state.arp2d, self.state.pos, old_pos, remove, add = newKey(self.state.arp2d, i, self.state.pos)
                self.ui.update_pattern(self.ui.field, self.state.arp2d, self.state.pos)
                if not self.state.mute:
                    self.network.send_note(self.state.arp_notes[i], config.DEFAULT_INTENSITY)
                
            elif new and not val:
                if not self.state.mute:
                    self.network.send_note(self.state.arp_notes[i], 0)

    def handle_menu_input(self, menu_manager):
        """Process menu navigation input"""
        rotation = 0  # Initialize rotation to 0
        if config.HW_VERSION == 1.1:
            rotation = self.hw.check_rotation(0, 512)
        elif config.HW_VERSION == 1.0:
            if self.hw.check_analog_rotation(config.ROTATION_CW):
                rotation = 1
            elif self.hw.check_analog_rotation(config.ROTATION_CCW):
                rotation = -1

        if rotation:
            menu_manager.handle_rotation(rotation)
        if self.hw.key_new(config.KEY_BACK):
            menu_manager.handle_back()
        if self.hw.key_new(config.KEY_SELECT):
            menu_manager.handle_select()

class ArpeggiatorPlayback:
    """Handles all playback-related operations for the arpeggiator"""
    def __init__(self, hw, state, ui, network):
        self.hw = hw
        self.state = state
        self.ui = ui
        self.network = network

    def update(self):
        """Update playback state"""
        if self.state.mode != config.PLAYBACK_STATES["playing"]:
            return

        now = time.monotonic()
        arp_tick = int((now - self.state.start_time) * self.state.time_to_tick % (self.state.ticks_per_beat*2))
        arp_pos_new = int(arp_tick * 2 / self.state.ticks_per_beat)
        
        if arp_pos_new > self.state.arp_pos or (self.state.arp_pos == len(self.state.arp_notes)-1 and arp_pos_new == 0):
            self._play_note(arp_pos_new)

    def _play_note(self, arp_pos_new):
        """Play a new note and update UI"""
        packet = bytearray()
        
        # Turn off previous note
        if self.state.old_note != 0:
            ch = config.INSTRUMENT_ID
            note = self.state.old_note
            intensity = 0
            packet.append(ord('l'))
            packet.append(ch)
            packet.append(note)
            packet.append(intensity)
            i = note % 12
            if not self.state.mute:
                if note in self.state.arp_notes:
                    self.hw.pixels[i] = 0x200010
                else:
                    self.hw.pixels[i] = 0x000000                            

        # Send new note
        ch = config.INSTRUMENT_ID
        note = self.state.arp_notes[arp_pos_new]
        intensity = config.DEFAULT_INTENSITY
        packet.append(ord('l'))
        packet.append(ch)
        packet.append(note)
        packet.append(intensity)
        i = note % 12
        if not self.state.mute:
            self.hw.pixels[i] = colorwheel(int(note / 12) * 20  & 255)
            self.network.esp.send(packet, self.network.peer_broadcast)
        
        # Update pattern display
        for n in self.state.arp2d[self.state.arp_pos]:
            self.ui.field.setBlock(n, self.state.arp_pos, 2)
        for n in self.state.arp2d[arp_pos_new]:
            self.ui.field.setBlock(n, arp_pos_new, 1)
            
        # Update state
        self.state.arp_pos = arp_pos_new
        self.state.old_note = note

        # Update display
        self.ui.display_manager.update_channel_info(ch, note, intensity)
        self.hw.display.refresh()

class Arpeggiator:
    """Main class coordinating all arpeggiator components"""
    def __init__(self, hw, display_manager, instrument_id, peer_broadcast):
        try:
            self.hw = hw
            self.display_manager = display_manager
            self.instrument_id = instrument_id
            self.peer_broadcast = peer_broadcast
            
            # Initialize components
            self.state = ArpeggiatorState()
            self.ui = ArpeggiatorUI(display_manager, hw)
            self.network = ArpeggiatorNetwork(hw, instrument_id, peer_broadcast)
            self.input_handler = ArpeggiatorInput(hw, self.state, self.ui, self.network)
            self.playback = ArpeggiatorPlayback(hw, self.state, self.ui, self.network)
            
            # Initialize menu
            self.menu_actions = {
                'send_song': lambda: self.network.packet_handler.send_song() if self.network.packet_handler else None,
                'set_channel': lambda: set_channel(),
                'show_my_ip': lambda: show_device_ip(),
                'send_pair': lambda: self.network.packet_handler.send_pair() if self.network.packet_handler else None,
                'show_paired_devices': lambda: show_connected_devices(),
                'set_mode': lambda mode_id: set_device_mode(mode_id)
            }
            self.menu_manager = MenuManager(config.MENU_FILE, display_manager, self.menu_actions)
            
            # Initialize state
            self.state.initialize_scale()
            self.send_pair()
        except Exception as e:
            report_error(display_manager, f"Arpeggiator initialization error: {e}", True)
            raise

    def run(self):
        """Main loop"""
        while True:
            try:
                # Update playback
                self.playback.update()

                # Handle network packets
                if self.network.esp:
                    try:
                        packet = self.network.packet_handler.read_packet()
                        if packet:
                            result = self.network.handle_packet(packet)
                            if result:
                                self._handle_packet_result(result)
                                    
                    except PacketReadError as e:
                        report_error(self.display_manager, f"Packet read error: {e}")
                    except Exception as e:
                        report_error(self.display_manager, f"Network error: {e}")

                # Handle input
                try:
                    self.input_handler.handle_key_input()
                    self.input_handler.handle_menu_input(self.menu_manager)
                except Exception as e:
                    report_error(self.display_manager, f"Input error: {e}")

            except KeyboardInterrupt:
                report_error(self.display_manager, "User interrupted")
                break
            except Exception as e:
                report_error(self.display_manager, f"Main loop error: {e}")
                # Continue running despite errors

    def _handle_packet_result(self, result):
        """Handle packet processing result"""
        try:
            packet_type, *args = result
            
            # Handle tick packet
            if packet_type == 'tick':
                tick = args[0]
                now_tick = int(self.state.time_to_tick * (time.monotonic() - self.state.start_time))
                tick_delta = tick - now_tick
                
            # Handle begin packet
            elif packet_type == 'begin':
                self.state.start_time = time.monotonic()
                self.state.mode = config.PLAYBACK_STATES["playing"]
                self.display_manager.show_debug_message("playing")
                
            # Handle stop packet
            elif packet_type == 'stop':
                self.state.mode = config.PLAYBACK_STATES["paused"]
                self.display_manager.show_debug_message("paused")
                if self.state.old_note != 0:
                    self.network.send_note(self.state.old_note, 0)
                    
            # Handle header packet
            elif packet_type == 'header':
                self.state.ticks_per_beat, self.state.max_ticks, self.state.tempo, numerator, self.state.denominator, nr_instruments = args
                self.state.tick_to_time = 60 * 4 / (self.state.tempo * self.state.ticks_per_beat * self.state.denominator)
                self.state.time_to_tick = (self.state.tempo * self.state.ticks_per_beat * self.state.denominator) / (60 * 4)
                song_length = self.state.max_ticks * self.state.tick_to_time
                self.state.mode = config.PLAYBACK_STATES["paused"]
                
            # Handle mute packet
            elif packet_type == 'mute':
                ch, intensity = args
                if ch == self.instrument_id:
                    self.state.mute = intensity
                    if self.state.mute:
                        for i in range(12):
                            self.hw.pixels[i] = (0,20,0)
                        self.display_manager.show_debug_message("muted")
                    else:
                        for i in range(12):
                            self.hw.pixels[i] = (0,0,0)
                        self.display_manager.show_debug_message(" ")
                        
            # Handle update packet
            elif packet_type == 'update':
                self.display_manager.show_debug_message("update")
                self.display_manager.show_debug_message(" ")
                redraw()
                self.display_manager.update_channel_info(0, 0, 0)
                
            # Handle reset packet
            elif packet_type == 'reset':
                self.state.reset()
                self.display_manager.show_debug_message("reset")
                self.ui.background.replace("arp0.bmp")
                self.display_manager.update_channel_info(0, 0, 0)
                if not self.state.mute:
                    self.ui.update_leds(self.state.arp_notes)
                self.ui.update_pattern(self.ui.field, self.state.arp2d, 0)
                
            # Handle clear packet
            elif packet_type == 'clear':
                id = args[0]
                if id == self.instrument_id or id == 255:
                    self.display_manager.show_debug_message("receiving")
                    self.state.arp_notes = [55, 60, 64, 60]
                    if not self.state.mute:
                        self.ui.update_leds(self.state.arp_notes)
                    self.state.mode = config.PLAYBACK_STATES["clear"]
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

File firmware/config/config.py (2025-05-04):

"""
config.py - Central configuration for hardware, display, and application settings.

This file contains all hardware pin assignments, display settings, and application-level
constants for the project. By centralizing these settings, you can easily adapt the codebase
to new hardware or change system-wide parameters in one place.

Sections:
- Device mode selection
- Common configuration (network, MIDI, etc.)
- Display settings
- Menu settings
- Hardware pin assignments (import board required)
- Mode-specific configuration (e.g., boss, chords)
- UI settings
- Audio settings
- Network settings

Usage:
Import this module as `import config.config as config` and use the variables directly.
Example: `config.AN1_PIN`, `config.DISPLAY_WIDTH`, `config.KEY_RESET`, etc.
"""
import board
# Device mode selection
# Choose the mode for this device (boss, pitch, time, chords, scale)
# MODE = "boss"
MODE = "pitch" # piano roll
# MODE = "pattern"  # drums / pad
# MODE = "chords" # chord progression
# MODE = "arp" # arpeggio


#------10|-------20|-------30|-------40|-------50|-------60|-------70|-------80|
# Mode-specific configuration
# These settings may override or extend the above depending on the selected MODE.
if MODE == 'boss':
    # Hardware settings
    HW_VERSION = 1.0
    KEY_RESET = 10
    KEY_PLAY_PAUSE = 11
    INSTRUMENT_ID = 1
    # Song settings
    SONG_NAME = "arpai"
    SONG_PATH = "assets/"

if MODE == 'pitch':    
    # LEAD:
    INSTRUMENT_ID = 2
    MEDIAN_OCTAVE = 7
    # BASS
    # INSTRUMENT_ID = 1
    # MEDIAN_OCTAVE = 5
    HW_VERSION = 1.1
    PLAYBACK_STATES = {
        "paused": 0,
        "playing": 1,
        "reset": 2,
        "clear": 3
    }
    FIELD_X_MAX = 40
    FIELD_Y_MAX = 16
    FIELD_TILE_WIDTH = 4
    FIELD_TILE_HEIGHT = 4    
    PIXELS_PER_BEAT = 4
    KEY_PCB_TO_NOTE = [1, 3, -1, 6, 8, 10, -1, 13, 0, 2, 4, 5, 7, 9, 11, 12]
    KEY_NOTE_TO_PCB = [8, 0, 9, 1, 10, 11, 3, 12, 4, 13, 5, 14, 2, 6, 7, 15]

if MODE == 'pattern':
    INSTRUMENT_ID = 3
    MEDIAN_OCTAVE = 1
    HW_VERSION = 1.1
    FIELD_X_MAX = 16
    FIELD_Y_MAX = 4
    FIELD_TILE_WIDTH = 10
    FIELD_TILE_HEIGHT = 10
    XSTART = 0
    YSTART = 0

    # Mode configuration
    MODES = {
        'paused': 0,
        'playing': 1,
        'reset': 2,
        'clear': 3
    }

    # Drum configuration
    DRUM_NOTES = [36, 38, 42, 57]  # bass, snare, hi-hat, crash
    DRUM_NAMES = [
        "bass (36)",
        "snare (38)",
        "closed hi-hat (42)",
        "crash (57)"
    ]

    # Menu configuration
    MENU_ACTIONS = {
        'send_song': lambda: None,  # Will be set in pattern.py
        'set_channel': lambda: None,
        'show_my_ip': lambda: None,
        'send_pair': lambda: None,
        'show_paired_devices': lambda: None,
        'set_mode': lambda mode_id: None
    }

if MODE == 'chords':
    INSTRUMENT_ID = 1
    MEDIAN_OCTAVE = 3           # (0:5 1:3 2:7)
    HW_VERSION = 1.0

if MODE == 'arp':
    INSTRUMENT_ID = 0
    MEDIAN_OCTAVE = 5
    HW_VERSION = 1.0
    FIELD_X_MAX = 8
    FIELD_Y_MAX = 8
    FIELD_TILE_WIDTH = 10
    FIELD_TILE_HEIGHT = 10
    PIXELS_PER_BEAT = 4
    PLAYBACK_STATES = {
        "paused": 0,
        "playing": 1,
        "reset": 2,
        "clear": 3
    }
    # Arpeggiator constants
    TICKS_PER_BEAT = 480
    MAX_TICKS = 47522
    TEMPO = 160
    DENOMINATOR = 4
    MAX_NOTE = 66
    MIN_NOTE = 55
    DEFAULT_ARP_PATTERN = [0, 1, 2, 1]
    XSTART = 40
    YSTART = 0
    BACKGROUND_Y_OFFSET = 81
    DEFAULT_TILE_VALUE = 3
    PATTERN_ACTIVE_TILE = 1
    PATTERN_CURRENT_TILE = 2
    LED_OFF_COLOR = 0x000000
    LED_ACTIVE_COLOR = 0x200010
    SCALE_C = 60
    SCALE_G = 55
    SCALE_A = 57
    SCALE_F = 65



#------10|-------20|-------30|-------40|-------50|-------60|-------70|-------80|
# Common configuration
# Network and MIDI settings
# MAC_BROADCAST: Broadcast MAC address for ESP-NOW
# EXTRA_PAYLOAD: Used to pad packets for robustness
# MIDI_CHANNEL: Default MIDI channel
# DEFAULT_INTENSITY: Default velocity for MIDI events
MAC_BROADCAST = b'\xFF\xFF\xFF\xFF\xFF\xFF'
EXTRA_PAYLOAD = "PAYLOAD TO MAKE A PACKET MORE ROBUST..."    
MIDI_CHANNEL = 1            # pick your MIDI channel here
DEFAULT_INTENSITY = 100     # midi intensity for live input

# Display settings
# DISPLAY_WIDTH/HEIGHT: Physical display dimensions in pixels
DISPLAY_WIDTH = 160
DISPLAY_HEIGHT = 128

# Menu settings
# MENU_FILE: Path to the menu configuration file
MENU_FILE = "config/menu.txt"

#------10|-------20|-------30|-------40|-------50|-------60|-------70|-------80|

if HW_VERSION == 1.0:
    NEOPIXEL_NUM = 12
    KEY_NUM = 16
    KEY_COL = 8
    NR_KEYS = 12
    KEY_BACK = 13
    KEY_SELECT = 12
    ROTATION_CW = 3
    ROTATION_CCW = 2
    ROTATION_TOP_CW = 1
    ROTATION_TOP_CCW = 0

    # Key matrix column pins (8 columns)
    COL_PINS = [
        board.IO8, board.IO7, board.IO6, board.IO5,
        board.IO4, board.IO3, board.IO2, board.IO1
    ]
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

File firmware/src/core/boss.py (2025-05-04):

#------10|-------20|-------30|-------40|-------50|-------60|-------70|-------80|
# ******************************************************************************
#    ______  ______         ____                 _____             _____
#    \     \|\     \    ____\_  \__         _____\    \       _____\    \
#     |     |\|     |  /     /     \       /    / \    |     /    / \    |
#     |     |/____ /  /     /\      |     |    |  /___/|    |    |  /___/|
#     |     |\     \ |     |  |     |  ____\    \ |   || ____\    \ |   ||
#     |     | |     ||     |  |     | /    /\    \|___|//    /\    \|___|/
#     |     | |     ||     | /     /||    |/ \    \    |    |/ \    \
#    /_____/|/_____/||\     \_____/ ||\____\ /____/|   |\____\ /____/|
#    |    |||     | || \_____\   | / | |   ||    | |   | |   ||    | |
#    |____|/|_____|/  \ |    |___|/   \|___||____|/     \|___||____|/
#                      \|____|
#
# Boss hadles the playback of a song and does the following:
#   > sends song events and tick packets wirelessly to other devices
#   > outputs audio playback using the i2s DAC and a basic synth engine
#   > outputs MIDI events over USB
#   > visualizes the song playback and allows channels to be muted
#
# Todo:
#   * add support for 1.1 hardware (only tested on 1.0)
#   * increase sample frequency of i2s mixer (16kHz samples and wavetable)
#   * replace broadcast with network discovery and setup?
#   * custom library for more efficient display handling
#   * custom library for audio rendering (wavetable and samples)
#
# Done:
#   250424:
#     x major code refactoring and cleanup:
#       directory structure, common modules, manager classes and error handling
#   250329:
#     x stop active notes on mute
#     x fix pcb to use i2s ldo instead of s2mini (and ground i2s scl)
#     x fix standalone playback (without USB midi)
#   241226:
#     x build menu system
#     x implement file header on synths
#   240929:
#     x implement live keyboard backchannel
#   240922:
#     x added keyboard and led_pixel support
#     x implemented mute on synths
# ******************************************************************************

import config.config as config
import espnow
from src.common import hw
import time
from src.common.audio import AudioManager
from src.common.ui import DisplayManager
from src.common.network import PacketHandler, NetworkError, PacketSendError, PacketReadError, SongSendError
from src.common.song import Song, SongPlayer
from src.common.menu import MenuManager

# ------10|-------20|-------30|-------40|-------50|-------60|-------70|-------80|

# load song
song_name = "arpai.bin"
#song_name = "ai&a_beat.bin"
song_name = song_name.split('.')
song_path = "assets/"

# ------10|-------20|-------30|-------40|-------50|-------60|-------70|-------80|

def initialize_audio():
    """Initialize audio system."""
    try:
        audio_manager = AudioManager(hw)
        return audio_manager
    except Exception as e:
        report_error(None, f"Audio init error: {e}", True)
        raise

def initialize_display():
    """Initialize display system."""
    try:
        display_manager = DisplayManager(hw.display, hw)
        display_manager.load_song_background(config.SONG_NAME)
        display_manager.create_position_sprite()
        display_manager.create_text_fields(config.SONG_NAME)
        
        return display_manager
    except Exception as e:
        report_error(None, f"Display init error: {e}", True)
        raise

def initialize_menu(display_manager):
    """Initialize menu system."""
    try:
        return MenuManager(config.MENU_FILE, display_manager)
    except Exception as e:
        report_error(display_manager, f"Menu init error: {e}", True)
        raise

def initialize_network():
    """Initialize network system."""
    try:
        if config.MODE == "boss":
            esp = espnow.ESPNow()
            BROADCAST = espnow.Peer(mac=config.MAC_BROADCAST)
            esp.peers.append(BROADCAST)
            packet_handler = PacketHandler(esp, config.INSTRUMENT_ID, BROADCAST)
            return esp, packet_handler
        return None, None
    except Exception as e:
        report_error(None, f"Network init error: {e}", True)
        raise

def handle_song_playback(player, display_manager):
    """Handle song playback updates."""
    try:
        result = player.update()
        if result:
            sprite_pos, ch, note, intensity = result
            if sprite_pos > player.sprite_last_pos:
                player.sprite_last_pos = sprite_pos
                display_manager.update_playback_position(sprite_pos)
            display_manager.update_channel_info(ch, note, intensity)
        return result
    except IndexError as e:
        # Handle out of range errors gracefully
        report_error(display_manager, "Playback position out of range")
        return None
    except Exception as e:
        report_error(display_manager, f"Playback error: {e}")
        return None

def handle_input(player, audio_manager, display_manager, menu_manager, song):
    """Handle user input."""
    try:
        # Handle reset button
        if hw.key_new(config.KEY_RESET):
            handle_reset(player, audio_manager, display_manager)
            return

        # Handle play/pause button
        if hw.key_new(config.KEY_PLAY_PAUSE):
            handle_play_pause(player, display_manager)
            return

        # Handle mute toggles
        for k in range(song.get_metadata('nr_instruments')):
            if hw.key_new(k):
                handle_mute_toggle(k, audio_manager, display_manager)
                return

        # Handle menu navigation
        handle_menu_navigation(menu_manager)
    except Exception as e:
        report_error(display_manager, f"Input error: {e}")
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
